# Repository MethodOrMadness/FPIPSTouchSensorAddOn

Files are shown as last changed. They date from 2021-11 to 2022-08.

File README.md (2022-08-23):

# FPIPSTouchSensorAddOn
So there is an issue, apparently FP ribbons dont like a short to ground, and requires a delay. It should still function if you populate u3, c3, and c6 and use a touch sensor on it though

an optional, semi-customizable board to add touch sensors to a funnyplaying AGB IPS screen ribbon, instead of using the SEL+R/L button combination

You can think of the touch sensors connected to P1 and P2 as "momentary" buttons, where as the touch sesnor on P3 act as a "toggle" switch(tap once to enable, tap again to disable)

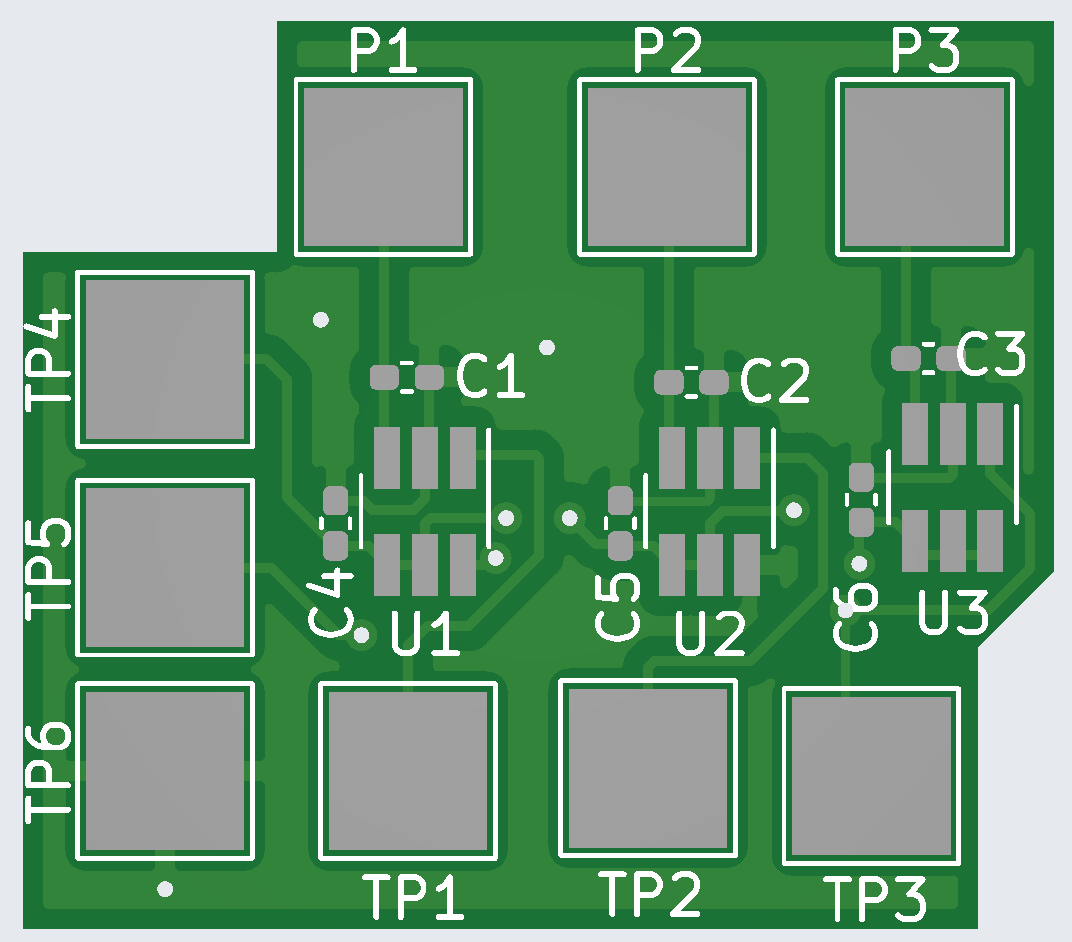
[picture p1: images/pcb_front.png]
PCB_FRONT

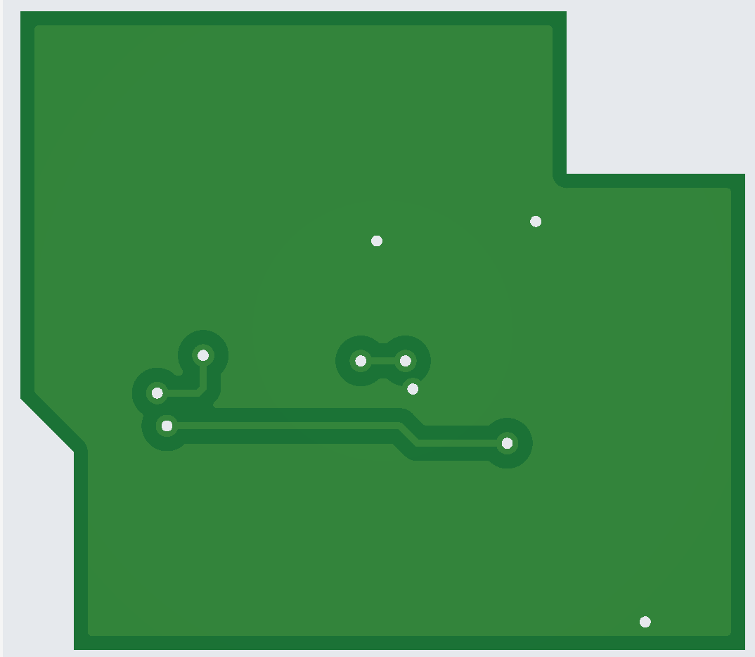
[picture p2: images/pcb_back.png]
PCB_BACK


I havent yet built this, I cannot verify that it actually works as intended, for building and installation I suggest referring to the schematic file, as it contains some notes.

## BOM

| RefDes | Part | Spec Sheet|
|---|-----|---|
|U1,U2,U3|TTP223-ba6| https://datasheet.lcsc.com/szlcsc/TTP223-BA6_C80757.pdf |
|C1,C2,C3|22pF Capacitor| N/A |
|C4,C5,C6|0.1uF Capacitor| N/A|

## Connections
| Pad |  Destination  |
|-----|---|
| TP1 | L On FP Ribbon|
| TP2 | R On FP Ribbon|
| TP3 | SEL On FP Ribbon|
| TP4 | 3.3v on AGB |
| TP5 | optinonal, tie to ground if you dont populate U3, C3, and C6 |
| TP6 | GND On FP Ribbon |
| P1 | Touch Sensor for decreasing brightness |
| P2 | Touch Sensor for increasing brightness |
| P3 | Touch sensor for select(optional, only needed if you populate U3, C3, and C6) |

## Notes
This should, in theory, work on other IPS kits too, though the connections might be different, I based this off of the FP kit.

## Credits
Zekfoo for catching some mistakes I made during the original board design process and for a third touch sensor(optinal) for the SEL pad

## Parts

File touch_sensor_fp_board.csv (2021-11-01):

Reference | Value | Footprint | Datasheet
U1 | ttp223-ba6 | Package_TO_SOT_SMD:SOT-23-6_Handsoldering | https://datasheet.lcsc.com/szlcsc/TTP223-BA6_C80757.pdf
U2 | ttp223-ba6 | Package_TO_SOT_SMD:SOT-23-6_Handsoldering | https://datasheet.lcsc.com/szlcsc/TTP223-BA6_C80757.pdf
U3 | ttp223-ba6 | Package_TO_SOT_SMD:SOT-23-6_Handsoldering | https://datasheet.lcsc.com/szlcsc/TTP223-BA6_C80757.pdf
C1 | 22pF | Capacitor_SMD:C_0402_1005Metric_Pad0.74x0.62mm_HandSolder
C2 | 22pF | Capacitor_SMD:C_0402_1005Metric_Pad0.74x0.62mm_HandSolder
C3 | 22pF | Capacitor_SMD:C_0402_1005Metric_Pad0.74x0.62mm_HandSolder
C4 | 0.1uF | Capacitor_SMD:C_0402_1005Metric_Pad0.74x0.62mm_HandSolder
C5 | 0.1uF | Capacitor_SMD:C_0402_1005Metric_Pad0.74x0.62mm_HandSolder
C6 | 0.1uF | Capacitor_SMD:C_0402_1005Metric_Pad0.74x0.62mm_HandSolder

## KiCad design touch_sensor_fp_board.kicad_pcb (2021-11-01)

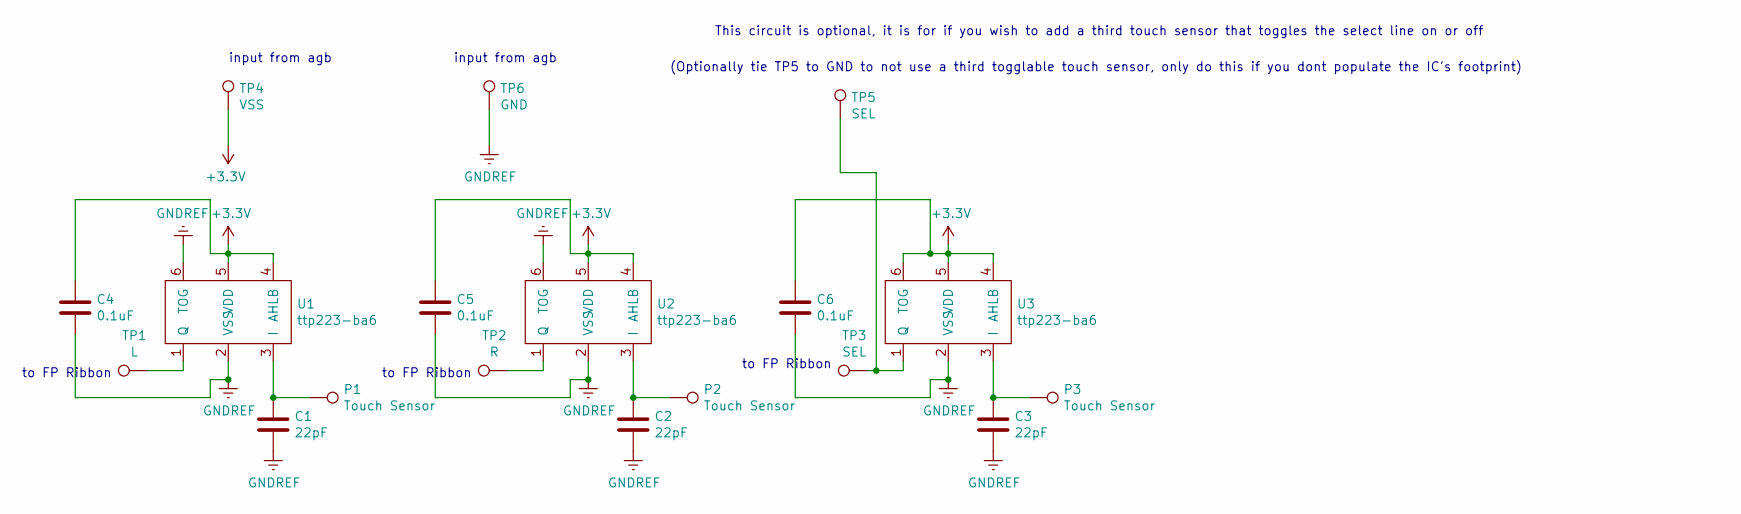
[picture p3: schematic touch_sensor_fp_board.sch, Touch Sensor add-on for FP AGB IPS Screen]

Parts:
C1, C2, C3: 22pF; C_0402_1005Metric_Pad0.74x0.62mm_HandSolder
C4, C5, C6: 0.1uF; C_0402_1005Metric_Pad0.74x0.62mm_HandSolder
P1, P2, P3: Touch Sensor; TestPoint_Pad_4.0x4.0mm
TP1: L; TestPoint_Pad_4.0x4.0mm
TP2: R; TestPoint_Pad_4.0x4.0mm
TP3, TP5: SEL; TestPoint_Pad_4.0x4.0mm
TP4: VSS; TestPoint_Pad_4.0x4.0mm
TP6: GND; TestPoint_Pad_4.0x4.0mm
U1, U2, U3: ttp223-ba6; SOT-23-6_Handsoldering

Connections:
+3V3: C4.1, C5.1, C6.1, TP4.1, U1.4 (AHLB), U1.5 (VDD), U2.4 (AHLB), U2.5 (VDD), U3.4 (AHLB), U3.5 (VDD), U3.6 (TOG)
GNDREF: C1.2, C2.2, C3.2, C4.2, C5.2, C6.2, TP6.1, U1.2 (VSS), U1.6 (TOG), U2.2 (VSS), U2.6 (TOG), U3.2 (VSS)
unnamed: C1.1, P1.1, U1.3 (I)
unnamed: C2.1, P2.1, U2.3 (I)
unnamed: C3.1, P3.1, U3.3 (I)
unnamed: TP1.1, U1.1 (Q)
unnamed: TP2.1, U2.1 (Q)
unnamed: TP3.1, TP5.1, U3.1 (Q)

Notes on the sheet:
input from agb
(Optionally tie TP5 to GND to not use a third togglable touch sensor, only do this if you dont populate the IC's footprint)
to FP Ribbon
This circuit is optional, it is for if you wish to add a third touch sensor that toggles the select line on or off

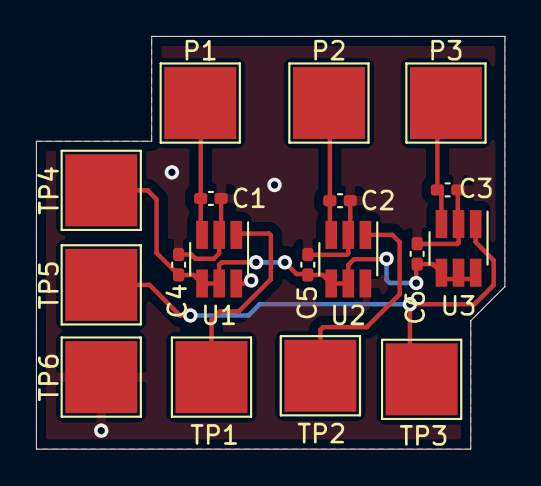
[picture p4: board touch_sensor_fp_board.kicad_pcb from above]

Board: 2 copper layers, 26.0 x 22.9 mm, 18 parts (0 on the bottom side), 8 nets.

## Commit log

2021-11-01 BOM
    BOM is in CSV format in the repo, but figured id add it here just incase, for easy refrencing
2021-11-01 updated wording on schematic
    [touch_sensor_fp_board.sch]
2021-11-01 added images of PCB

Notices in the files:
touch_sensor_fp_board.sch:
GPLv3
